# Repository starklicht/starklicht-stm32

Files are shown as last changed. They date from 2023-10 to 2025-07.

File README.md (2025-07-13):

# ✨ Starklicht STM32F401 Firmware

Welcome to the **Starklicht** firmware repository!  
This project powers creative lighting for **movie makers, theater productions, and professional lighting installations**—where dynamic, reliable, and customizable effects matter most.

### Documentation

Full Documentation is on our website: https://starklicht.net/docs/intro/

---

## 🌟 What is Starklicht?

Starklicht is a modular, STM32-based lighting controller for professional and creative environments.  
It enables **dynamic lighting animations**, **battery management**, and **intuitive user control** for demanding applications.

---

## Files

You can download all files for Hardware (PCB, 3D Print) at [Cults3D](https://cults3d.com/de/modell-3d/gadget/starklicht)!

> **Note**: We will update the Circuit diagrams for the PCB etc. in the next days!

---
# 🛠️ Starklicht Build – Estimated Cost Breakdown

| **Category** | **Details / Notes** | **Estimated Cost (USD)** |
|---|---|---|
| **PCBs** | Main controller, driver boards, etc. | ~$100 |
| **Electronic Components** | LED chip, power supply, heatsink, fan | ~$65 |
| **3D Printed Parts** | Filament for case and mounting parts | ~$7 |
| **Shipping & Taxes** | Depends on your region and import fees | ~$27 |
| | | |
| **🔢 Estimated Total** | *(Before time investment)* | **~$199** |

---

## 🔍 A Few Important Notes

- **Economies of Scale**  
  Buying components and PCBs in bulk can *significantly reduce* the cost per unit.

- **Time Investment Not Included**  
  This estimate does **not** account for the time spent sourcing, soldering, or assembling. Expect a hands-on, rewarding process!

- **Component Flexibility**  
  This is an open-source project. You’re free to substitute parts depending on what you have or prefer—which can impact final costs.

---

## 📖 Documentation

We are working on a detailed Documentation right now, work in Progress 👷‍♀️. Just click on [Wiki](https://github.com/starklicht/starklicht-stm32/wiki) to check it out. It will tell you, how it's made, how to 3D-Print components, etc.

---

## 🛠️ Building the Lamp

✅ The entire Lamp housing can be 3D Printed. We will provide them very soon here!

We also provide PCB's fitting exactly into the housing. You can order both PCB's and Lamp housings on https://www.starklicht.net ! 😊

For detailed instructions on Hardware (PCBs, Wiring, Housing), refer to the Wiki [Hardware](https://github.com/starklicht/starklicht-stm32/wiki/Hardware). This chapter will be updated the next weeks.

### Components

- Microcontroller: STM32F401CCU6 Blackpill Board
- Display: 1.3" 128x64 OLED Display (SH1106 Driver)
- Bluetooth Module: HM-10 BLE Module
- LEDs: High-power RGB LEDs
-  Potentiometers: For manual control of color and brightness
-  Buttons: For preset selection and other functions
-  Fan: For cooling the LEDs and driver
-  Current Sensor: To monitor power consumption
-  Temperature Sensors: To monitor the temperature of the LEDs and driver

---

## 🚀 Features

- 🎨 **Customizable Lighting Animations:** Create and control stunning effects for any scene.
- 🔋 **Battery Management:** Real-time monitoring and smart power handling.
- 🖥️ **User Interface:** Graphical display and button input for easy, on-the-fly adjustments.
- 💾 **EEPROM Support:** Save and recall your favorite effects and settings.
- 🧩 **Modular C++ Design:** Clean, maintainable codebase with reusable classes.

---

## 🧩 Software Architecture

Editor _ Mermaid Chart-2025-06-26-141957

- **Main Application:** Entry point (`main.c`, `starklicht.cpp`)
- **Controller:** Central logic and coordination
- **Display:** Handles graphical output (u8g2 library)
- **Animation:** Manages lighting effects
- **Battery:** Monitors and manages power
- **Messaging:** Communication and event handling over BLE

---

## 📚 Third-Party Libraries

This project utilizes the following open-source libraries:

- **u8g2:** A monochrome graphics library for OLEDs and LCDs.
  - License: [BSD 2-Clause](LICENSES/U8G2_LICENSE.txt)

---
## ✉️ Messaging Protocol

### Design Philosophy

The Starklicht BLE protocol is designed for maximum efficiency and simplicity, tailored for the constraints of Bluetooth Low Energy and embedded microcontrollers.

*   **Lightweight:** We use a raw binary format instead of text (like JSON). This makes messages extremely compact, ensuring most commands fit within a single 20-byte BLE packet to reduce latency and power consumption.
*   **Fast to Parse:** The fixed `[ID][DATA]` structure allows the device's firmware to read values directly from memory offsets without needing a complex parser, saving precious CPU cycles and RAM.
*   **Embedded-Friendly:** The protocol uses integer math where possible to avoid computationally expensive floating-point operations on the microcontroller.

This protocol is a living document. We are open to suggestions and changes to improve its functionality and performance.

---

### Message API Reference

All multi-byte values are encoded in **Big Endian** format.

#### **1. Color Message (ID: `0`)**
Sets a solid color.

| Byte | Field | Description |
| :--- | :---- | :--- |
| 0 | ID | `0` |
| 1 | Red | Red channel (0-255) |
| 2 | Green | Green channel (0-255) |
| 3 | Blue | Blue channel (0-255) |

*   **Example (Set color to Blue):** `[0, 0, 0, 255]`

---

#### **2. Animation Message (ID: `1`)**
Sends a color gradient animation.

| Bytes | Field | Description |
| :--- | :--- | :--- |
| 0 | ID | `1` |
| 1 | Interpolation | `0`=Linear, `1`=Ease |
| 2 | Time Factor | `0`=Once, `1`=Repeat, `2`=Mirror |
| 3 | Duration (Mins) | Duration minutes part (0-59) |
| 4 | Duration (Secs) | Duration seconds part (0-59) |
| 5 | Duration (Centis) | Duration milliseconds/10 (0-99) |
| 6 | Color Point Count | Number of color points (`N`) that follow |
| 7+ | Color Points | `N` blocks of Color Point data (5 bytes each) |

**Color Point Structure (5 bytes per point):**

| Offset | Field | Description |
| :--- | :--- | :--- |
| +0 | Red | Red channel (0-255) |
| +1 | Green | Green channel (0-255) |
| +2 | Blue | Blue channel (0-255) |
| +3, +4 | Position | 16-bit integer (`position * 1000`) |

---

#### **3. Brightness Message (ID: `2`)**
Sets the overall brightness.

| Byte | Field | Description |
| :--- | :--- | :--- |
| 0 | ID | `2` |
| 1 | Brightness | Brightness value (0-100) |

*   **Example (Set brightness to 50%):** `[2, 50]`

---

#### **4. Fade Message (ID: `3`)**
Fades to a target color over a duration.

| Byte | Field | Description |
| :--- | :--- | :--- |
| 0 | ID | `3` |
| 1, 2 | Duration | 16-bit duration in milliseconds |
| 3 | Red | Target Red channel (0-255) |
| 4 | Green | Target Green channel (0-255) |
| 5 | Blue | Target Blue channel (0-255) |
| 6 | Ease Flag | `1` for ease, `0` for linear |

*   **Example (Fade to purple over 1.5s):** `[3, 5, 220, 128, 0, 128, 1]`

---

#### **5. Save/Load Message (ID: `4`)**
Saves the current state to a preset button or loads a state from it.

| Byte | Field | Description |
| :--- | :--- | :--- |
| 0 | ID | `4` |
| 1 | Save Flag | `1` to **save**, `0` to **load** |
| 2 | Button Index | The button index to use (0-3) |

*   **Example (Save to Button 1):** `[4, 1, 0]`
*   **Example (Load from Button 2):** `[4, 0, 1]`

---

## 🏁 Getting Started

### Prerequisites

- [STM32CubeIDE](https://www.st.com/en/development-tools/stm32cubeide.html)
- [STM32CubeProgrammer](https://www.st.com/en/development-tools/stm32cubeprog.html)
- CMake or Make (optional, for advanced builds)

### Setup

❗️ This setup works, but is not optimal yet. If you have any Ideas, don't hesitate to add a PR!

1. Clone this repository:
   ```sh
   git clone https://github.com/yourusername/starklicht-stm32.git
   ```
2. Open STM32CubeIDE
3. Select `File` → `New` → `STM32 Project From Existing STM32CubeMX Configuration File`
4. A new Popup with Project Creation Wizard appears
5. `File`: `Browse` → Select the `.ioc` File of this Repository
6. Set Targeted Language to `C++`
7. Click `Finish`
8. Replace `Inc`, `Src` and `Startup` in `Core` with the ones from this Repo
9. Replace `STM32F401CCUX_FLASH.ld` with the one from the Repo

Now you can Build the Project

### Building and Flashing

1. Build the project in STM32CubeIDE.
2. Connect the STM32F410RB board via USB to UART.
3. Use STM32CubeProgrammer to flash the firmware onto the MCU.

---

## 🎬 Example Use Cases

- 🎥 **Movie Sets:** Sync lighting with camera cues for dramatic effects.
- 🎭 **Theater:** Dynamic scene changes and mood lighting.
- 💡 **Installations:** Interactive or automated light shows.

---

## 🤝 Contributing

We welcome your ideas and improvements!  
See `CONTRIBUTING.md` for guidelines.

---

## 📄 License

GLP3.0 – see [LICENSE](LICENSE) for details.

---

## 📬 Contact

Questions or support?  
Email us: [kontakt@starklicht.net](mailto:kontakt@starklicht.net)

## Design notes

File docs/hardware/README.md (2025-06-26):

# Hardware section

### 3D Print

We recommend 3d printing with ABS+ - this is a very durable and heat resistant PLA.

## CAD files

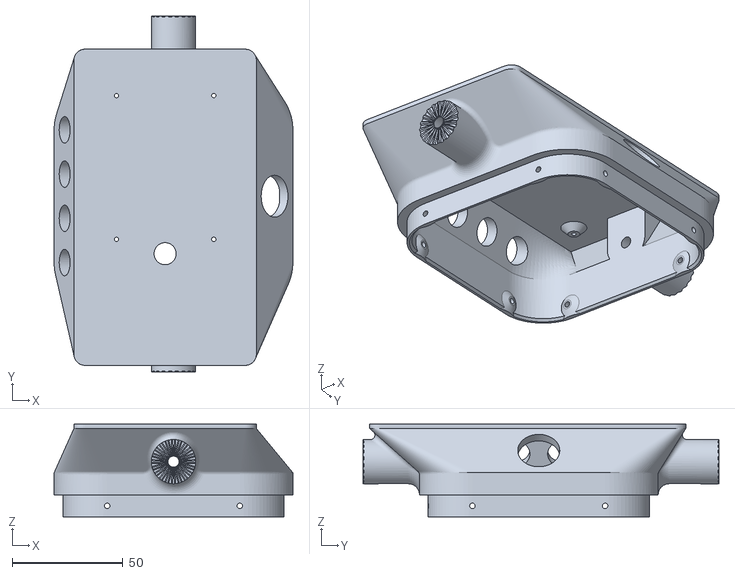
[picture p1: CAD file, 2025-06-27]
3d-print/starklicht-v3-back.stl
108.0 x 161.0 x 42.0

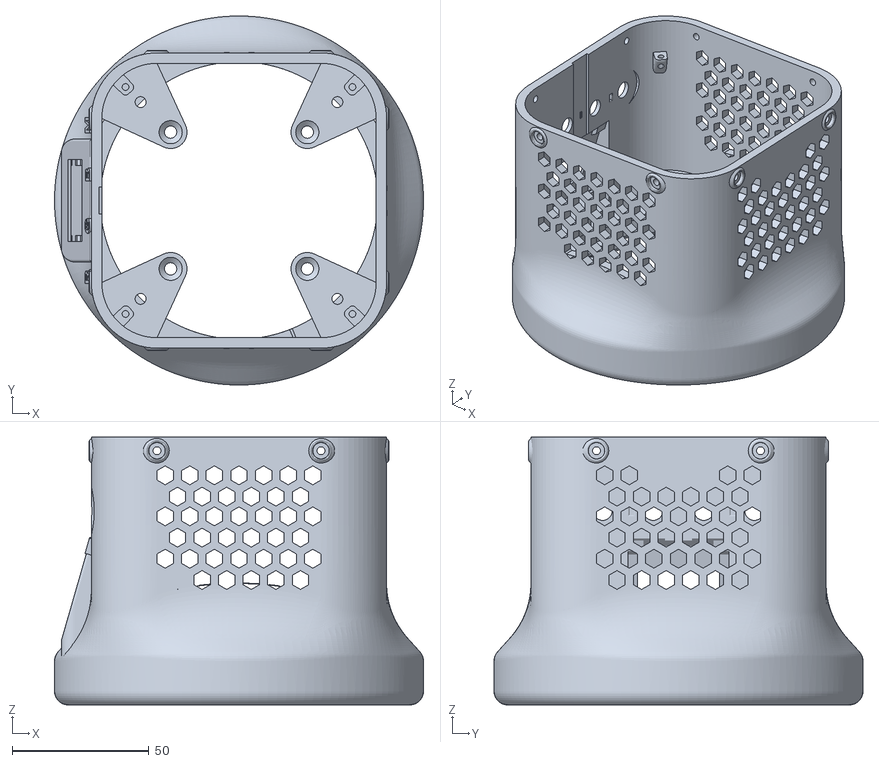
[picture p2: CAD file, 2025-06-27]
3d-print/starklicht-v3-front.stl
135.0 x 135.0 x 98.0

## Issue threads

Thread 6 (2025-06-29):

feat: ADD DMX communication

starklicht, 2025-06-29:
##  Description:
  Let's get DMX communication working! We can repurpose USART2 (using PA2 for TX and PA3 for RX) and PB2 for the DMX Transmit Enable (DE) pin.

##  Why this works:
  While PA2 and PA3 are currently configured as analog inputs (likely for temperature sensing of separate LEDs, given their labels TEMP_DG and TEMP_DB), our software isn't actively using those specific analog readings
  from analogInputs[2] and analogInputs[3]. This means we can "hijack" these pins: the PCBs already provide these connections to the driver boards, but we'll need to carefully remove their pins from the driver
  connections and insert another pin to wire them to our DMX transceiver instead. PB2 is completely free.

##   Future Considerations:
  For a cleaner solution, it would be ideal to update the main controller PCB to properly route DMX signals. This would also involve reconfiguring the driver LED connections, as the current setup uses pins that are
  now ideal for DMX. But for now, this "hijack" method gets us DMX without a full board redesign.

 ## Action Items (for the person implementing):
   1. STM32CubeIDE:
       * Disable ADC for PA2/PA3.
       * Configure USART2 (PA2 TX, PA3 RX) for DMX (250k baud, 8N2).
       * Configure PB2 as GPIO Output (DMX_DE).
       * Generate code.
   2. Hardware:
       * Disconnect PA2/PA3 from driver PCBs.
       * Wire PA2/PA3 and PB2 to the DMX transceiver.
   3. Code: Implement DMX transmit/receive logic.

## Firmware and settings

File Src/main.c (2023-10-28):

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
/* Includes ------------------------------------------------------------------*/
#include "main.h"
/* USER CODE BEGIN Includes */
#include "starklicht.h"
/* USER CODE END Includes */

/* USER CODE BEGIN PD */
#define USE_BUTTONS 1
/* USER CODE END PD */

ADC_HandleTypeDef hadc1;
DMA_HandleTypeDef hdma_adc1;

SPI_HandleTypeDef hspi1;

TIM_HandleTypeDef htim4;

UART_HandleTypeDef huart1;

void SystemClock_Config(void);
static void MX_GPIO_Init(void);
static void MX_DMA_Init(void);
static void MX_TIM4_Init(void);
static void MX_SPI1_Init(void);
static void MX_ADC1_Init(void);
static void MX_USART1_UART_Init(void);
/* USER CODE BEGIN 0 */
static u8g2_t u8g2;

uint8_t buffer[512];
int numChars = 128;
uint8_t current_char;
int num_messages = 0;
uint8_t escapeSign = 0;
int num_chars;
uint16_t ndx = 0;
uint8_t payload = 0;
uint8_t endMarker = '\n';
uint16_t analogInputs[10];

uint8_t u8x8_stm32_gpio_and_delay(U8X8_UNUSED u8x8_t *u8x8,
                                  U8X8_UNUSED uint8_t msg, U8X8_UNUSED uint8_t arg_int,
                                  U8X8_UNUSED void *arg_ptr)
{
  switch (msg)
  {
  case U8X8_MSG_GPIO_AND_DELAY_INIT:
    HAL_Delay(1);
    break;
  case U8X8_MSG_DELAY_MILLI:
    HAL_Delay(arg_int);
    break;
  case U8X8_MSG_GPIO_DC:
    HAL_GPIO_WritePin(DC_GPIO_Port, DC_Pin, arg_int);
    break;
  case U8X8_MSG_GPIO_RESET:
    HAL_GPIO_WritePin(RST_GPIO_Port, RST_Pin, arg_int);
    break;
  case U8X8_MSG_GPIO_CS:
    HAL_GPIO_WritePin(CS_GPIO_Port, CS_Pin, arg_int);

    break;
  }
  return 1;
}

uint8_t u8x8_byte_4wire_hw_spi(u8x8_t *u8x8, uint8_t msg, uint8_t arg_int,
                               void *arg_ptr)
{
  switch (msg)
  {
  case U8X8_MSG_BYTE_SEND:
    HAL_SPI_Transmit(&hspi1, (uint8_t *)arg_ptr, arg_int, 10000);
    break;
  case U8X8_MSG_BYTE_INIT:
    break;
  case U8X8_MSG_BYTE_SET_DC:
    HAL_GPIO_WritePin(DC_GPIO_Port, DC_Pin, arg_int);
    break;
  case U8X8_MSG_BYTE_START_TRANSFER:
    break;
  case U8X8_MSG_BYTE_END_TRANSFER:
    break;
  default:
    return 0;
  }
  return 1;
}
/* USER CODE END 0 */

/**
 * @brief  The application entry point.
 * @retval int
 */
int main(void)
{
  /* MCU Configuration--------------------------------------------------------*/

  /* Reset of all peripherals, Initializes the Flash interface and the Systick. */
  HAL_Init();

  /* Configure the system clock */
  SystemClock_Config();

  /* Initialize all configured peripherals */
  MX_GPIO_Init();
  MX_DMA_Init();
  MX_TIM4_Init();
  MX_SPI1_Init();
  MX_ADC1_Init();
  MX_USART1_UART_Init();
  /* USER CODE BEGIN 2 */
  HAL_UART_Receive_IT(&huart1, &current_char, 1);

  HAL_TIM_PWM_Start(&htim4, TIM_CHANNEL_1);
  HAL_TIM_PWM_Start(&htim4, TIM_CHANNEL_2);
  HAL_TIM_PWM_Start(&htim4, TIM_CHANNEL_3);
  HAL_TIM_PWM_Start(&htim4, TIM_CHANNEL_4);

  TIM2->CCR1 = 0;
  if (HAL_ADC_Start_DMA(&hadc1, (uint32_t *)analogInputs, 10) != HAL_OK)
  {
    /* Start Conversation Error */
    Error_Handler();
  }

  for (int i = 0; i < 3; i++)
  {
    HAL_GPIO_TogglePin(LED1_GPIO_Port, LED1_Pin);
    HAL_Delay(10);
  }

  u8g2_Setup_sh1106_128x64_noname_f(&u8g2, U8G2_R0, u8x8_byte_4wire_hw_spi, u8x8_stm32_gpio_and_delay);
  u8g2_InitDisplay(&u8g2);
  u8g2_SetFlipMode(&u8g2, 0);
  u8g2_SetPowerSave(&u8g2, 0);
  setup(&analogInputs, &u8g2, USE_BUTTONS);
  int batteryEnergy = getBatteryEnergy();
  char num[10];
  sprintf(num, "%dWh", batteryEnergy);

  for (uint8_t i = 78; i > 38; i--)
  {
    u8g2_FirstPage(&u8g2);
    u8g2_SetFont(&u8g2, u8g2_font_luBS12_te);
    u8g2_DrawStr(&u8g2, 8, i, "STARKLICHT");
    u8g2_SetFont(&u8g2, u8g2_font_helvR08_te);
    u8g2_DrawStr(&u8g2, 48, 8, num);
    u8g2_NextPage(&u8g2);
    HAL_Delay(2);
  }
  HAL_Delay(500);

  /* USER CODE END 2 */

  /* Infinite loop */
  /* USER CODE BEGIN WHILE */

  while (1)
  {
    u8g2_FirstPage(&u8g2);
    do
    {
      loop(HAL_GetTick());
    } while (u8g2_NextPage(&u8g2));
    /* USER CODE END WHILE */

    /* USER CODE BEGIN 3 */
  }
  /* USER CODE END 3 */
}

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
/* USER CODE BEGIN 4 */
void HAL_UART_RxCpltCallback(UART_HandleTypeDef *huart)
{
  if (huart->Instance == USART1)
  {
    if (payload == 1 && current_char == endMarker)
    {
      buffer[ndx] = '\0';
      ndx = 0;
      payload = 0;
      // TODO: Controller updaten
      num_messages++;
      HAL_UART_Receive_IT(&huart1, &current_char, 1);
      parseMessage(&buffer);
      // build message
      return;
    }
    if ((current_char != escapeSign) | (payload == 1))
    {
      buffer[ndx] = current_char;
      ndx++;
      if (ndx >= numChars)
      {
        ndx = numChars - 1;
      }
      payload = 0;
    }
    else
    {
      payload = 1;
    }
    HAL_UART_Receive_IT(&huart1, &current_char, 1);
  }
}
/* USER CODE END 4 */
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


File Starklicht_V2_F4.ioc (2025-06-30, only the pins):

Mcu.UserName=STM32F401CCUx
PA0-WKUP.GPIO_Label=TEMP_LED
PA0-WKUP.Signal=SharedAnalog_PA0
PA1.GPIO_Label=TEMP_DR
PA1.Signal=SharedAnalog_PA1
PA10.Signal=USART1_RX
PA12.GPIO_Label=CS
PA12.Signal=GPIO_Output
PA13.Signal=SYS_JTMS-SWDIO
PA14.Signal=SYS_JTCK-SWCLK
PA15.GPIO_Label=DC
PA15.Signal=GPIO_Output
PA2.GPIO_Label=TEMP_DG
PA2.Signal=SharedAnalog_PA2
PA3.GPIO_Label=TEMP_DB
PA3.Signal=SharedAnalog_PA3
PA4.GPIO_Label=RED
PA4.Signal=SharedAnalog_PA4
PA5.GPIO_Label=GREEN
PA5.Signal=SharedAnalog_PA5
PA6.GPIO_Label=BLUE
PA6.Signal=SharedAnalog_PA6
PA7.GPIO_Label=MASTER
PA7.Signal=SharedAnalog_PA7
PA8.GPIO_Label=BT_STATE
PA8.Signal=GPIO_Input
PA9.Signal=USART1_TX
PB0.GPIO_Label=CURR
PB0.Signal=SharedAnalog_PB0
PB1.GPIO_Label=BATTERY_VOLTAGE
PB1.Signal=SharedAnalog_PB1
PB12.GPIO_Label=BT4
PB12.Signal=GPIO_Input
PB13.GPIO_Label=BT3
PB13.Signal=GPIO_Input
PB14.GPIO_Label=BT2
PB14.Signal=GPIO_Input
PB15.GPIO_Label=BT1
PB15.Signal=GPIO_Input
PB3.Signal=SPI1_SCK
PB4.GPIO_Label=RST
PB4.Signal=GPIO_Output
PB5.Signal=SPI1_MOSI
PB6.GPIO_Label=R_LED
PB6.Signal=S_TIM4_CH1
PB7.GPIO_Label=G_LED
PB7.Signal=S_TIM4_CH2
PB8.GPIO_Label=B_LED
PB8.Signal=S_TIM4_CH3
PB9.GPIO_Label=PWM_LUEFTER
PB9.Signal=S_TIM4_CH4
PC13-ANTI_TAMP.GPIO_Label=LED1
PC13-ANTI_TAMP.Signal=GPIO_Output

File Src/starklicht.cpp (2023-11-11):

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
/* Includes ------------------------------------------------------------------*/
#include "starklicht.h"
//#include "usb_device.h"
/* USER CODE BEGIN Includes */
#include "starklicht_library/display.h"
#include "starklicht_library/controller.h"
#include "starklicht_library/poti_input.h"
#include "starklicht_library/serialization.h"
#include "starklicht_library/runningtimecalculation.h"
#include "starklicht_library/ButtonController.h"
#include "starklicht_library/OneButton.h"

Display *display;
PotiInput *potiInput;
Serialization *serialization;
Controller *controller;
FanControl *fanControl;
RunningTimeCalculation *runningTime;
ButtonController *buttonController;

OneButton *a;
OneButton *b;
OneButton *c;
OneButton *d;

void click(int button)
{
	if (button == controller->getButton())
	{
		if (controller->getMode() == Controller::BUTTON_ANIMATION || controller->getMode() == Controller::BUTTON_COLOR)
		{
			controller->setMode(Controller::POTIS);
			return;
		}
	}
	Controller::MODE m = controller->animatorFromEEPROM(button);
	if (m != Controller::NOT_DEFINED)
	{
		controller->setMode(m);
		display->setActiveButton(controller->getButton());
	}
}

void clickA()
{
	click(0);
}

void clickB()
{
	click(1);
}

void clickC()
{
	click(2);
}

void clickD()
{
	click(3);
}

void setup_internal(uint16_t *dma_array, u8g2_t *u8g2, uint8_t activateButtons = 1)
{
	display = new Display(u8g2);
	potiInput = new PotiInput(dma_array, true);
	serialization = new Serialization();
	controller = new Controller(0, 0, 0, nullptr, potiInput, dma_array);
	fanControl = new FanControl(dma_array, 0, 1, 2, 3);
	buttonController = new ButtonController();
	if (activateButtons == 1)
	{
		a = new OneButton(BT1_GPIO_Port, BT1_Pin, 0);
		b = new OneButton(BT2_GPIO_Port, BT2_Pin, 0);
		c = new OneButton(BT3_GPIO_Port, BT3_Pin, 0);
		d = new OneButton(BT4_GPIO_Port, BT4_Pin, 0);
		a->attachClickStart(clickA);
		b->attachClickStart(clickB);
		c->attachClickStart(clickC);
		d->attachClickStart(clickD);
	}

	controller->update(0);
	// Default battery

	runningTime = new RunningTimeCalculation(dma_array, 8, 8, 8, 9, getBatteryEnergy());
}

uint16_t map(uint16_t x, uint16_t in_min, uint16_t in_max, uint16_t out_min, uint16_t out_max)
{
	return (x - in_min) * (out_max - out_min) / (in_max - in_min) + out_min;
}

Color *loop_internal(uint32_t tick)
{
	// Update the controller
	// Temperature
	float temp = fanControl->update();

	controller->setIsCritical(temp >= 65);

	a->tick();
	b->tick();
	c->tick();
	d->tick();

	controller->update(tick);

	display->setMode(controller->getMode());
	display->setColor(controller->getColor());
	display->setActiveButton(controller->getButton());
	// display->setDebug(dma_array);
	display->setBatteryPercentage(controller->getBatteryPercentage());
	display->masterLocked = !controller->masterFloating;
	display->colorsLocked = controller->getMode() != Controller::MODE::POTIS;
	if (HAL_GPIO_ReadPin(BT_STATE_GPIO_Port, BT_STATE_Pin))
	{
		display->setBluetoothState(true);
	}
	else
	{
		display->setBluetoothState(false);
	}

	// Fan Control
	uint16_t fanSpeed = 4095;
	if (temp > 30)
	{
		fanSpeed = map(temp, 30, 60, 0, 4095);
		if (fanSpeed > 4095)
		{
			fanSpeed = 4095;
		}
		else if (fanSpeed < 0)
		{
			fanSpeed = 0;
		}
	}
	else
	{
		fanSpeed = 0;
	}

	display->setTemperature(fanControl->update());

	display->setIsCritical(controller->isCritical());
	// display->setRemainingMinutes(runningTime->getMinutesLeft());

	TIM4->CCR3 = (uint16_t(controller->getColor()->r * (float)(controller->getColor()->master) / 4095.0f));
	TIM4->CCR1 = (uint16_t(controller->getColor()->b * (float)(controller->getColor()->master) / 4095.0f));
	TIM4->CCR2 = (uint16_t(controller->getColor()->g * (float)(controller->getColor()->master) / 4095.0f));
	TIM4->CCR4 = 4095 - fanSpeed;

	runningTime->update();
	display->setRemainingMinutes(runningTime->getMinutesLeft());

	display->update();

	return controller->getColor();
}

void parseMessage_internal(uint8_t *buffer)
{
	MyMessage *m = serialization->deserializeMessage(buffer);
	m->execute(controller);
}

int getBatteryEnergy_internal()
{
	int batteryEnergy = 95;
	if (controller->getBatteryEnergy() > 0)
	{
		batteryEnergy = controller->getBatteryEnergy();
	}
	return batteryEnergy;
}

extern "C"
{
	void setup(uint16_t *dma_array, u8g2_t *u8g2, uint8_t activateButtons)
	{
		setup_internal(dma_array, u8g2, activateButtons);
	}

	int getBatteryEnergy()
	{
		return getBatteryEnergy_internal();
	}

	void loop(uint32_t t)
	{
		loop_internal(t);
	}

	void parseMessage(uint8_t *buffer)
	{
		parseMessage_internal(buffer);
	}
}

/************************ (C) COPYRIGHT STMicroelectronics *****END OF FILE****/

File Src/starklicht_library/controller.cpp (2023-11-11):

//
// Created by Jannis Jahr on 2019-08-18.
//

#include "starklicht_library/controller.h"
#include "math.h"

/**
 * Change the color to a static color and animate
 * @param c new color
 */
void Controller::changeColor(Color *c)
{
    mode = COLOR;
    currentColor.r = c->r;
    currentColor.g = c->g;
    currentColor.b = c->b;
    currentColor.master = c->master;
}

void Controller::changeOnlyColor(Color *c)
{
    mode = COLOR;
    currentColor.r = c->r;
    currentColor.g = c->g;
    currentColor.b = c->b;
}

/**
 * Set a new animation
 * @param pingpong Pingpong
 * @param interpolation Interpolation type as int
 * @param n Number of keyframes
 * @param c Array of keyframes as pointer
 * @param time Duration in milliseconds
 */
void Controller::changeKeyframes(bool pingpong, int interpolation, int n, Keyframe *c[32], int time, bool repeating, bool seamless)
{
    mode = ANIMATION;
    animator->setInterpolatorType(interpolation);
    animator->setRepeating(repeating);
    // TODO: Erweitern
    if (!seamless)
    {
        animator->setPong(true);
        animator->setStartPoint(HAL_GetTick());
    }
    animator->setNumberOfFrames(n);
    animator->setPingpong(pingpong);
    animator->setDuration(time);
    for (int i = 0; i < n; i++)
    {
        animator->setKeyframe(i, c[i]->getFraction(), c[i]->getValue()->r, c[i]->getValue()->g, c[i]->getValue()->b,
                              c[i]->getValue()->master);
    }
}

void Controller::fadeInto(int duration, Color *endColor, int interpolation)
{
    mode = ANIMATION;
    animator->setNumberOfFrames(2);
    animator->setStartPoint(HAL_GetTick());
    animator->setRepeating(false);
    animator->setKeyframe(0, 0, currentColor.r, currentColor.g, currentColor.b, currentColor.master);
    animator->setDuration(duration);
    animator->setInterpolatorType(interpolation);
    animator->setPingpong(false);
    animator->setKeyframe(1, 1, endColor->r, endColor->g, endColor->b, endColor->master);
}

/**
 * Constructor of Controller
 * @param rpin Arduino pinz6  of red
 * @param gpin Arduino pin of green
 * @param bpin Arduino pin of blue
 * @param masterpin Arduino pin of white
 */
Controller::Controller(uint8_t rpin, uint8_t gpin, uint8_t bpin, FanControl *_fanControl, PotiInput *_potiControls, uint16_t *_dma_array)
{
    this->rpin = rpin;
    this->gpin = gpin;
    this->bpin = bpin;

    currentColor = Color();
    lastPotiValues = Color();
    // Full brightness to begin with
    brightness = 1;
    animator = new Animator(0, true);

    mode = POTIS;

    // OUTPUT RGB LAMP

    on = true;
    testDuration = 2000;
    this->dma_array = dma_array;

    this->potis = _potiControls;
    this->fanControl = _fanControl;
    this->dma_array = _dma_array;
    this->redCurrent = new CurrentSensor(dma_array, 8);
    this->batterySensor = new VoltageSensor(dma_array, 9);
    // this->flasher =  new FlashEEPROM();
}

bool Controller::willChangeToPotis()
{
    Color *currentPotiValues = potis->getColor();
    return fabs(lastPotiValues.r - currentPotiValues->r) > potiActivationThreshold ||
           fabs(lastPotiValues.g - currentPotiValues->g) > potiActivationThreshold ||
           fabs(lastPotiValues.b - currentPotiValues->b) > potiActivationThreshold;
}

/**
 * Update the controller and get the color of the animator
 * @param value Desired milliseconds
 * @return color of the animator
 */
void Controller::update(unsigned long value)
{

    if (critical)
    {
        resetColor();
        return;
    }

    Color *cur;
    Color *potiValues = potis->update();
    if (willChangeToPotis())
    {
        setMode(MODE::POTIS);
    }
    if (fabs(lastPotiValues.master - potis->getColor()->master) > potiActivationThreshold)
    {
        masterFloating = true;
    }
    switch (mode)
    {
    case POTIS:
        cur = potiValues;
        // setColorBrightness(cur, brightness);
        currentColor.r = cur->r;
        currentColor.g = cur->g;
        currentColor.b = cur->b;
        currentColor.master = cur->master;
        break;
    case ANIMATION:
        // TODO
        cur = animator->getValue(value);
        currentColor.r = cur->r;
        currentColor.g = cur->g;
        currentColor.b = cur->b;
        // setColorBrightness(animator->getValue(value), brightness);
        break;
    case COLOR:
        // setColorBrightness(&currentColor, brightness);
        break;
    case BUTTON_ANIMATION:
        cur = animator->getValue(value);
        currentColor.r = cur->r;
        currentColor.g = cur->g;
        currentColor.b = cur->b;
        break;
    case BUTTON_COLOR:
        // TODO
        currentColor.master = potis->update()->master;
        // setColorBrightness(&currentColor, brightness);
        break;
    }
    if (masterFloating)
    {
        currentColor.master = potiValues->master;
    }
}

/**
 * Constrain a color to a range
 */
float Controller::constrain(float a, float b, float c)
{
    return 0; // TODO
}

/**
 * Set the overall brightness of the lamp
 * @param br
 */
void Controller::setBrightness(uint16_t br)
{
    if (mode == POTIS)
    {
        setMode(MODE::COLOR);
    }
    potis->update();
    masterFloating = false;
    lastPotiValues.r = potis->getColor()->r;
    lastPotiValues.g = potis->getColor()->g;
    lastPotiValues.b = potis->getColor()->b;
    lastPotiValues.master = potis->getColor()->master;
    currentColor.master = br;
}

Color *Controller::getColor()
{
    return &currentColor;
}

/**
 * Change the lamp state (switch on or off)
 * @param newState new lamp state
 */
/*void Controller::changeOnState(boolean newState) {
    on = newState;
    if (!on) {
        // Set current color to complete black
        setColor(0, 0, 0, 0);
    }
}*/

/**
 * Let the potis control the lamp
 * @param pot If the potis should control the lamp
 */
void Controller::setMode(MODE m)
{
    // CACHE POTI VALUES if
    potis->update();
    lastPotiValues.r = potis->getColor()->r;
    lastPotiValues.g = potis->getColor()->g;
    lastPotiValues.b = potis->getColor()->b;
    lastPotiValues.master = potis->getColor()->master;
    Controller::mode = m;
}

Controller::MODE Controller::getMode() const
{
    return mode;
}

/**
 * sets lamp off
 */
void Controller::resetColor()
{
    currentColor.r = 0;
    currentColor.g = 0;
    currentColor.b = 0;
    currentColor.master = 0;
}

int Controller::batteryPower()
{
    return 100;
}
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

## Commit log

2023-11-11 feat: set max temperature to 65°C and fix critical bug
    [controller.cpp, starklicht.cpp]
2025-06-26 fix: ioc was wrong
    [Starklicht_V2_F4.ioc]
2025-06-27 feat: add 3d print files
    [starklicht-v3-back.stl, starklicht-v3-front.stl]
2025-06-27 docs: add 3d print readme
2025-06-28 docs: add hint for circuit diagrams

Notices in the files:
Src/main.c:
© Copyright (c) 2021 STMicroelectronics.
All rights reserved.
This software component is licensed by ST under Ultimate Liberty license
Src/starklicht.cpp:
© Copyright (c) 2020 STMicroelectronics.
